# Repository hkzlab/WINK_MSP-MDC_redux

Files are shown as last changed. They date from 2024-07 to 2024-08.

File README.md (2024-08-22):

# MSP-MDC Redux

## DISCLAIMER

Any use of this project is **under your own responsibility**.
You will be responsible of checking the correct construction and functionality of your board.
By using this project You will agree that I cannot be held responsible if it will destroy any of your devices, damage your computer, burn down your house or whatever.

## Introduction

Wink is a 1985, breakout-style, arcade game by Midcoin.

The game uses off-the-shelf components for everything, but a bunch of circuitry, called the MSP-MDC module, that acts both as CPU and as 
security (scrambling addresses accessed by the CPU), is placed on 3 sandwiched PCBs encased in epoxy.
This was made to thwart bootleggers, but if something within this epoxied block dies, the whole game stops working.

I painstakingly pulled the block apart and chipped away the epoxy to recover the schematic.

This project contains files to build a compatible board that can be plugged in place of the original MSP-MDC.

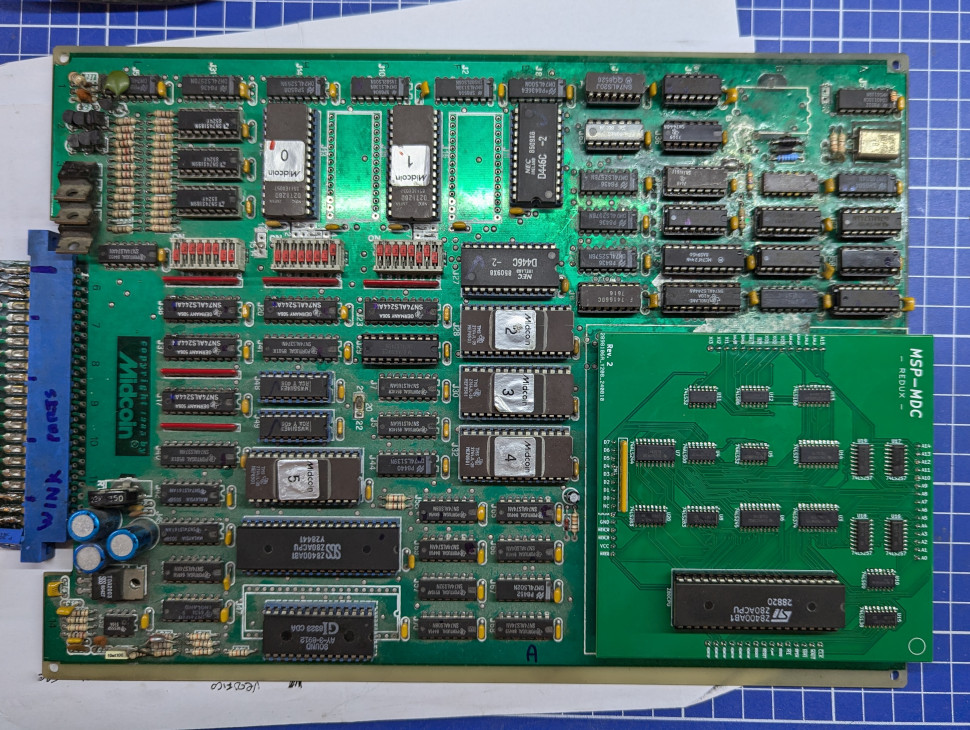
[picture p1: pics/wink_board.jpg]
Wink PCB + MSP-MDC redux


## Hardware

The board was designed with [KiCad](https://kicad.org/) EDA.

You can order boards directly from [PCBWay](https://www.pcbway.com/project/shareproject/MSP_MDC_Redux_c4e8a048.html)!

### Bill of Materials

| Component | Qty | Type / Value | Notes |
| --- | --- | --- | --- |
| C1 - C14 | 19  | 100nF / 1206 / ceramic | |
| R1, R2 |  2  | 1K / 1206 | |
| RN1 |  1  | 9-pin bussed 10K resistor array| |
| |  4  | 4x15pin 2.54mm straight headers| Mount on the 4 sides of the module |
| U2 |  1  | DIP-40 Z80A CPU | It's a good idea to socket this |
| U3, U14 |  2  | 74LS374 SO-20 | 5.3x12.6mm |
| U4 |  1  | 74ALS00 SOIC-14 | 3.9x8.7mm |
| U5 |  1  | 74ALS32 SOIC-14 | 3.9x8.7mm |
| U6 |  1  | 74LS245 SO-20 | 5.3x12.6mm |
| U7 |  1  | 74ALS244 SO-20 | 5.3x12.6mm |
| U8, U20 |  2  | 74LS283 SOIC-16 | 3.9x9.9mm |
| U10 |  1  | 74LS00 SOIC-14 | 3.9x8.7mm |
| U11 |  1  | 74LS32 SOIC-14 | 3.9x8.7mm |
| U12 |  1  | 74LS86 SOIC-14 | 3.9x8.7mm |
| U13 |  1  | 74LS166 SOIC-16 | 3.9x9.9mm |
| U15 |  1  | 74LS138 SOIC-16 | 3.9x9.9mm |
| U16 - U19 |  4  | 74LS257 SOIC-16 | 3.9x9.9mm |

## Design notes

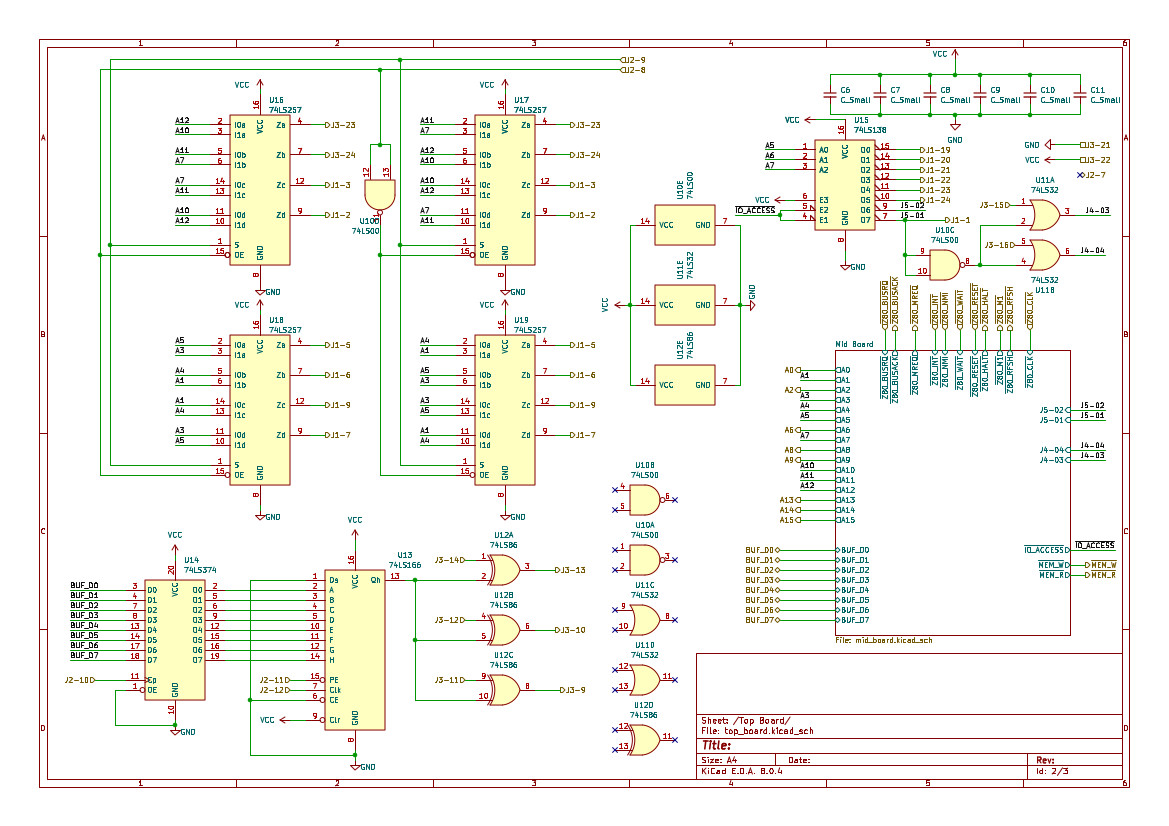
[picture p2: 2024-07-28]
MSP-MDC-Top Board.jpg

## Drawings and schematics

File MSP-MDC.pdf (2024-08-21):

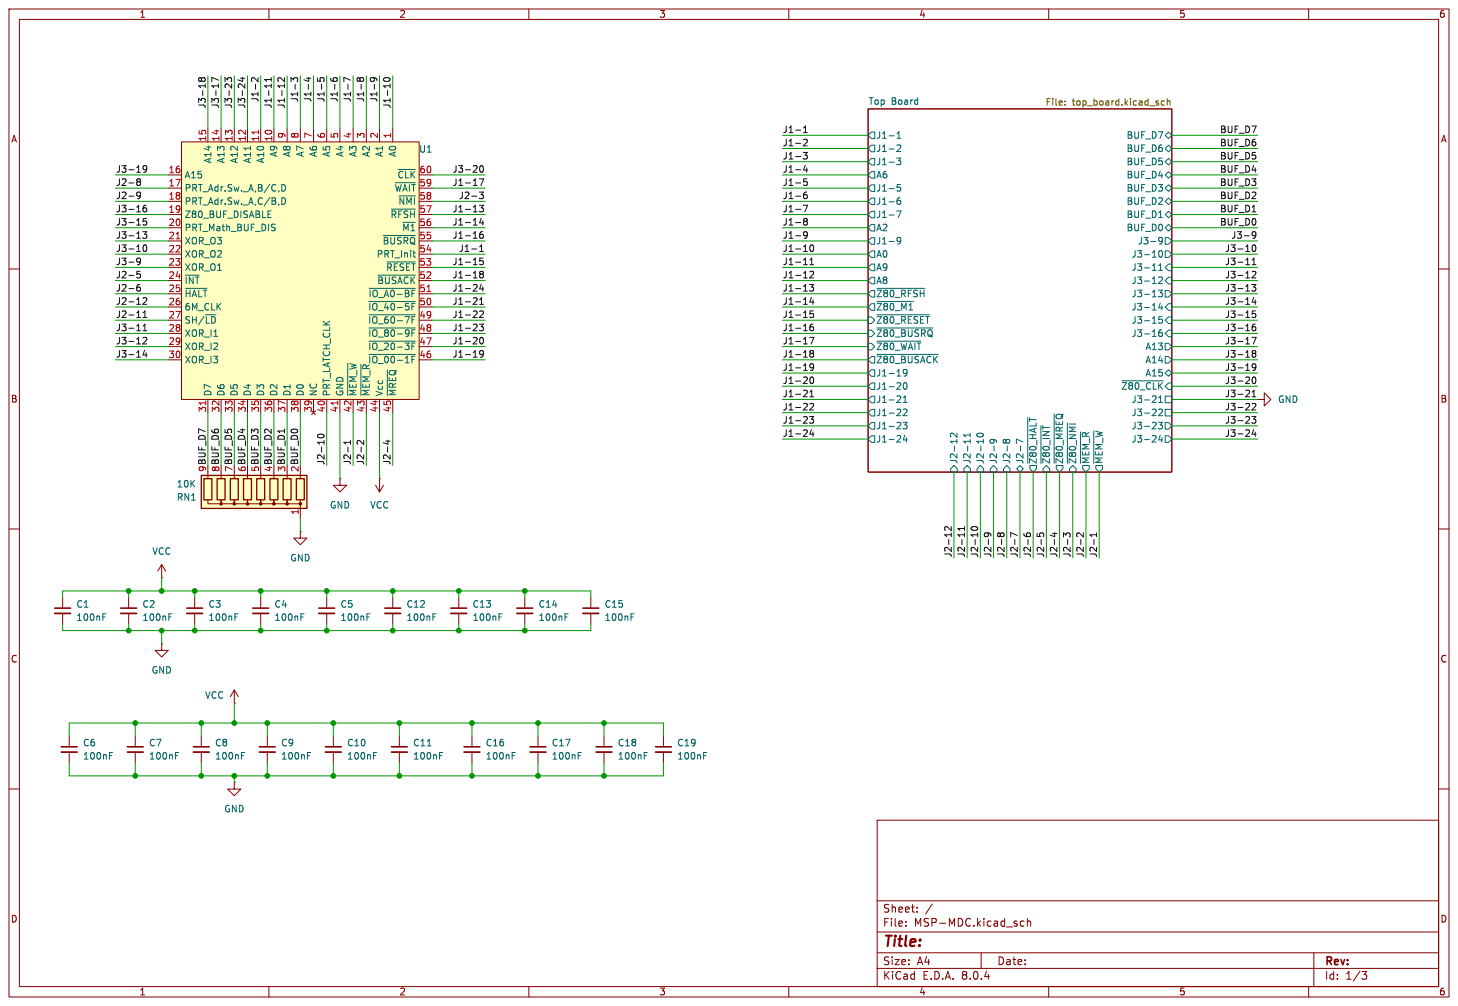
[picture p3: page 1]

5 ~{IO_40-5F}50 ~{IO_A0-BF}51 ~{BUSACK}52 ~{RESET} 53 PRT_Init 54 ~{BUSRQ}55 ~{M1}56 ~{RFSH} 57 ~{NMI}58 ~{WAIT} 59 A5

Id: 1/3 Title: File: MSP-MDC.kicad_sch Sheet: /

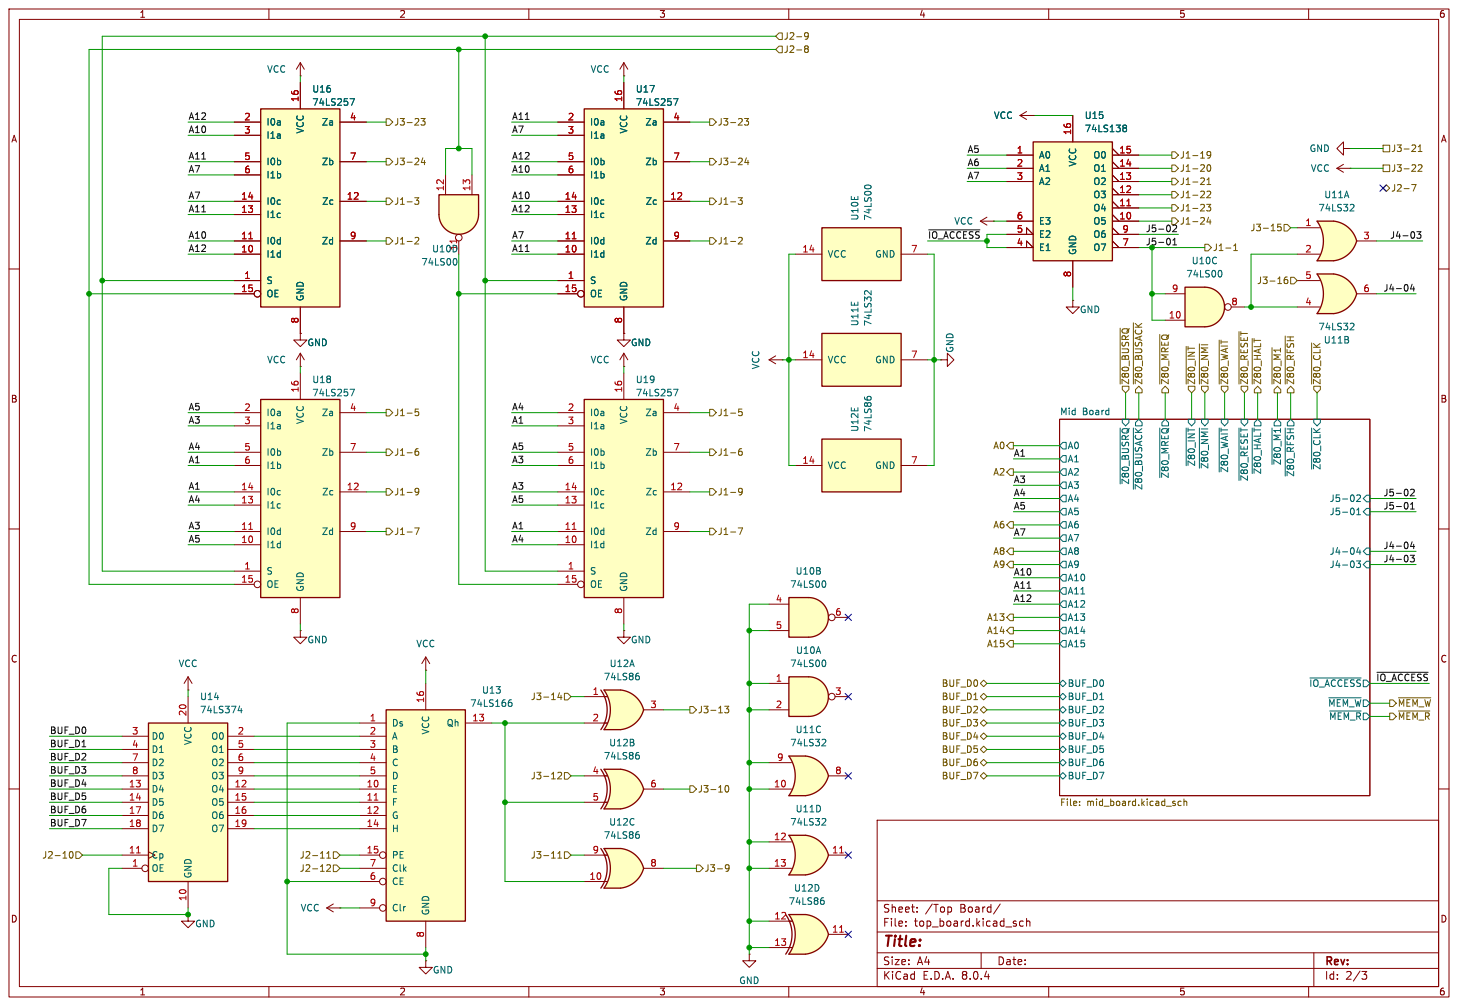
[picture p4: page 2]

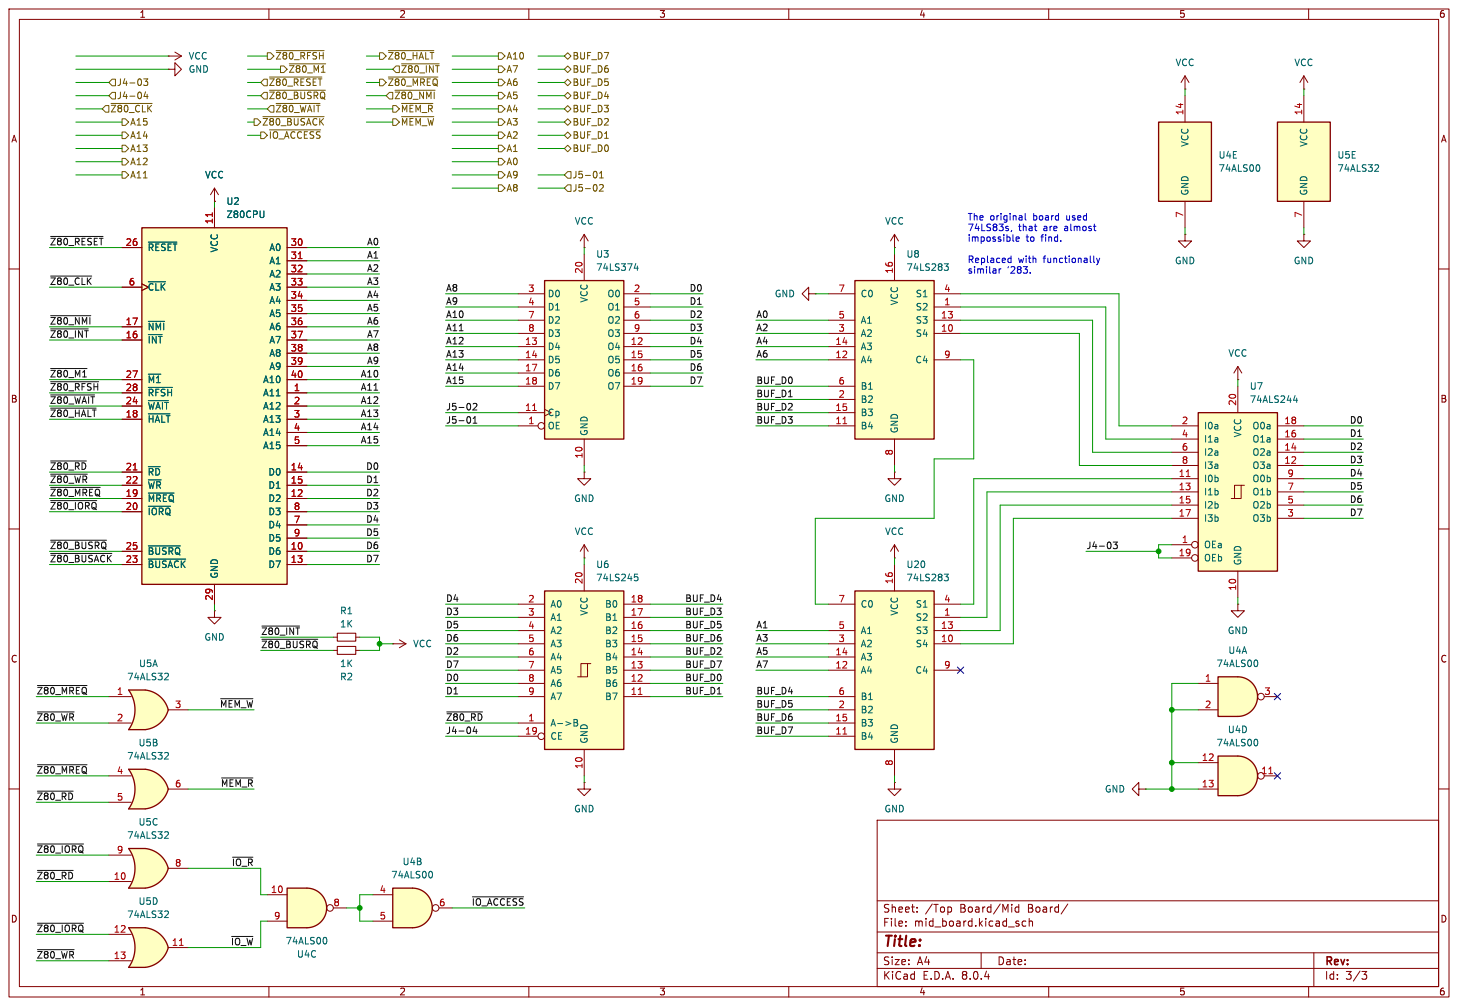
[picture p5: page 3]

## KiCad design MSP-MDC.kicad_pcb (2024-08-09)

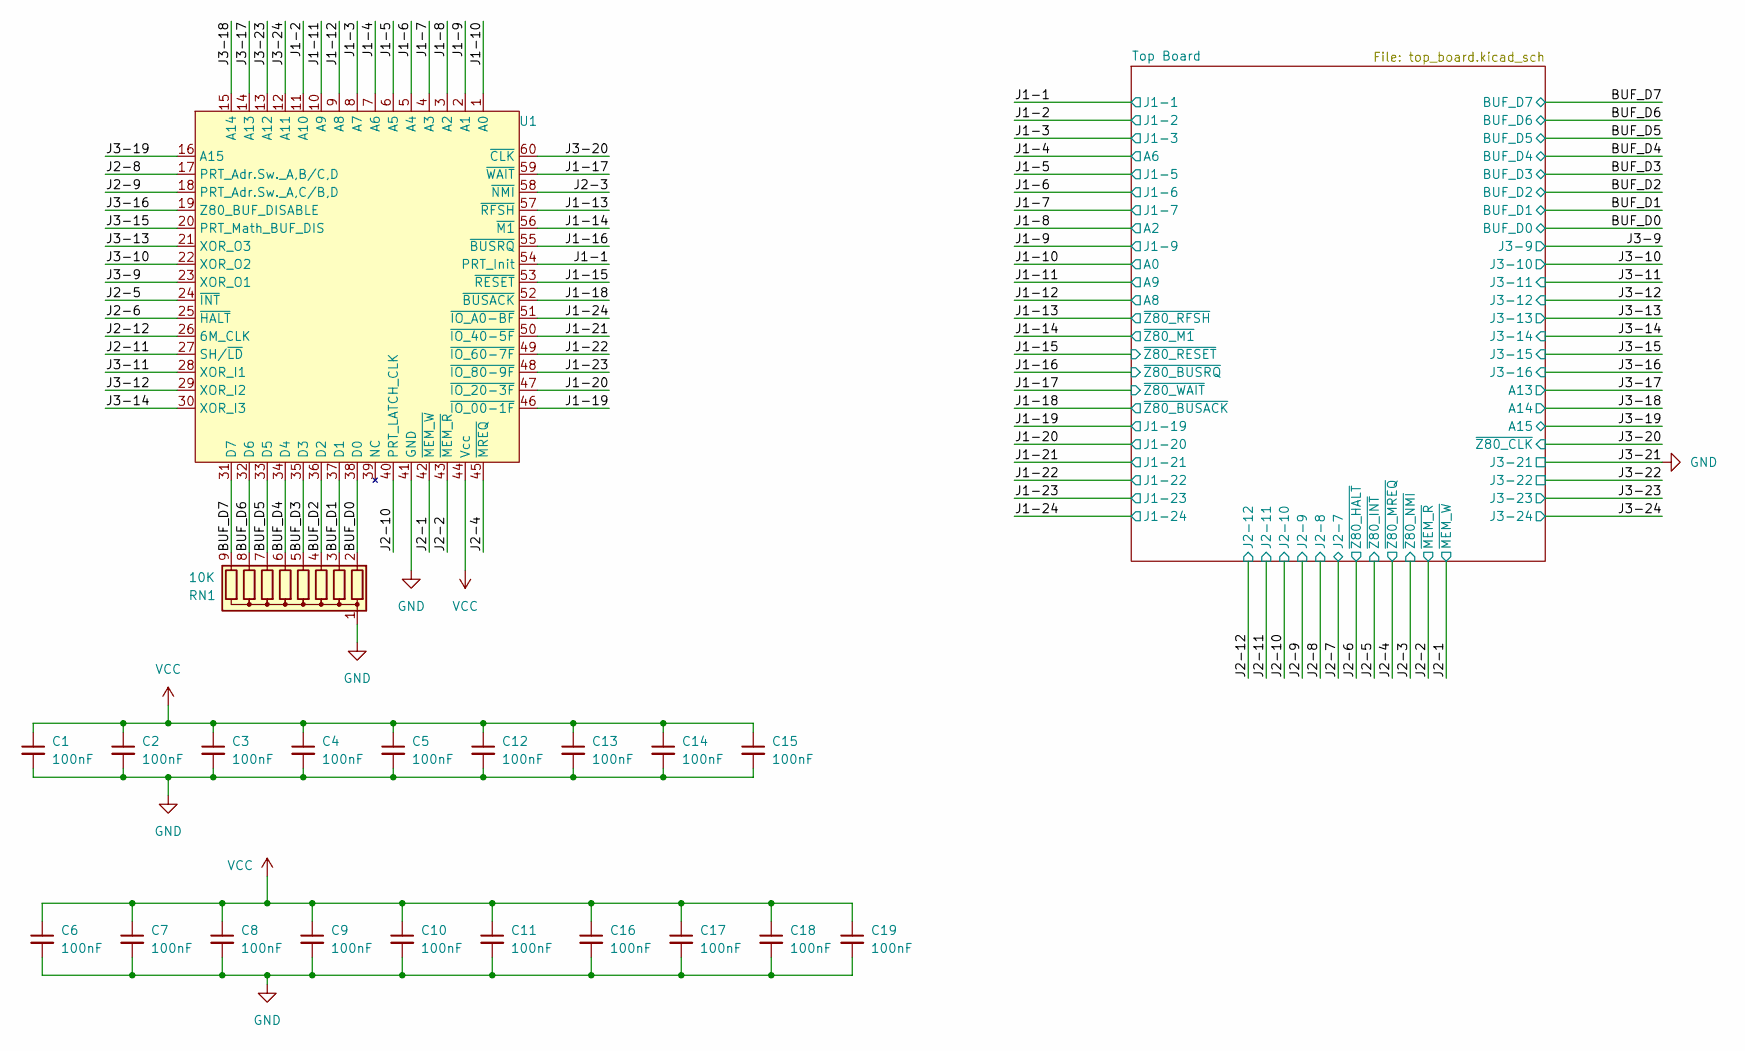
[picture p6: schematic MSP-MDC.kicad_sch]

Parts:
C1, C2, C3, C4, C5, C6, C7, C8, C9, C10, C11, C12, C13, C14, C15, C16, C17, C18, C19: 100nF; C_1206_3216Metric_Pad1.33x1.80mm_HandSolder
RN1: 10K; R_Array_SIP9
U1: MSP-MDC

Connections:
/BUF_D0: RN1.2 (R1), U1.38 (D0); also elsewhere on the board
/BUF_D1: RN1.3 (R2), U1.37 (D1); also elsewhere on the board
/BUF_D2: RN1.4 (R3), U1.36 (D2); also elsewhere on the board
/BUF_D3: RN1.5 (R4), U1.35 (D3); also elsewhere on the board
/BUF_D4: RN1.6 (R5), U1.34 (D4); also elsewhere on the board
/BUF_D5: RN1.7 (R6), U1.33 (D5); also elsewhere on the board
/BUF_D6: RN1.8 (R7), U1.32 (D6); also elsewhere on the board
/BUF_D7: RN1.9 (R8), U1.31 (D7); also elsewhere on the board
/J1-1: U1.54 (PRT_Init); also elsewhere on the board
/J1-2: U1.11 (A10); also elsewhere on the board
/J1-3: U1.8 (A7); also elsewhere on the board
/J1-4: U1.7 (A6); also elsewhere on the board
/J1-5: U1.6 (A5); also elsewhere on the board
/J1-6: U1.5 (A4); also elsewhere on the board
/J1-7: U1.4 (A3); also elsewhere on the board
/J1-8: U1.3 (A2); also elsewhere on the board
/J1-9: U1.2 (A1); also elsewhere on the board
/J1-10: U1.1 (A0); also elsewhere on the board
/J1-11: U1.10 (A9); also elsewhere on the board
/J1-12: U1.9 (A8); also elsewhere on the board
/J1-13: U1.57 (~RFSH); also elsewhere on the board
/J1-14: U1.56 (~M1); also elsewhere on the board
/J1-15: U1.53 (~RESET); also elsewhere on the board
/J1-16: U1.55 (~BUSRQ); also elsewhere on the board
/J1-17: U1.59 (~WAIT); also elsewhere on the board
/J1-18: U1.52 (~BUSACK); also elsewhere on the board
/J1-19: U1.46 (~IO_00-1F); also elsewhere on the board
/J1-20: U1.47 (~IO_20-3F); also elsewhere on the board
/J1-21: U1.50 (~IO_40-5F); also elsewhere on the board
/J1-22: U1.49 (~IO_60-7F); also elsewhere on the board
/J1-23: U1.48 (~IO_80-9F); also elsewhere on the board
/J1-24: U1.51 (~IO_A0-BF); also elsewhere on the board
/J2-1: U1.42 (~MEM_W); also elsewhere on the board
/J2-2: U1.43 (~MEM_R); also elsewhere on the board
/J2-3: U1.58 (~NMI); also elsewhere on the board
/J2-4: U1.45 (~MREQ); also elsewhere on the board
/J2-5: U1.24 (~INT); also elsewhere on the board
/J2-6: U1.25 (~HALT); also elsewhere on the board
/J2-8: U1.17 (PRT_Adr.Sw._A,B/C,D); also elsewhere on the board
/J2-9: U1.18 (PRT_Adr.Sw._A,C/B,D); also elsewhere on the board
/J2-10: U1.40 (PRT_LATCH_CLK); also elsewhere on the board
/J2-11: U1.27 (SH/~LD); also elsewhere on the board
/J2-12: U1.26 (6M_CLK); also elsewhere on the board
/J3-9: U1.23 (XOR_O1); also elsewhere on the board
/J3-10: U1.22 (XOR_O2); also elsewhere on the board
/J3-11: U1.28 (XOR_I1); also elsewhere on the board
/J3-12: U1.29 (XOR_I2); also elsewhere on the board
/J3-13: U1.21 (XOR_O3); also elsewhere on the board
/J3-14: U1.30 (XOR_I3); also elsewhere on the board
/J3-15: U1.20 (PRT_Math_BUF_DIS); also elsewhere on the board
/J3-16: U1.19 (Z80_BUF_DISABLE); also elsewhere on the board
/J3-17: U1.14 (A13); also elsewhere on the board
/J3-18: U1.15 (A14); also elsewhere on the board
/J3-19: U1.16 (A15); also elsewhere on the board
/J3-20: U1.60 (~CLK); also elsewhere on the board
/J3-23: U1.13 (A12); also elsewhere on the board
/J3-24: U1.12 (A11); also elsewhere on the board
GND: C1.2, C2.2, C3.2, C4.2, C5.2, C6.2, C7.2, C8.2, C9.2, C10.2, C11.2, C12.2, C13.2, C14.2, C15.2, C16.2, C17.2, C18.2, C19.2, RN1.1 (common), U1.41 (GND); also elsewhere on the board
VCC: C1.1, C2.1, C3.1, C4.1, C5.1, C6.1, C7.1, C8.1, C9.1, C10.1, C11.1, C12.1, C13.1, C14.1, C15.1, C16.1, C17.1, C18.1, C19.1, U1.44 (Vcc); also elsewhere on the board

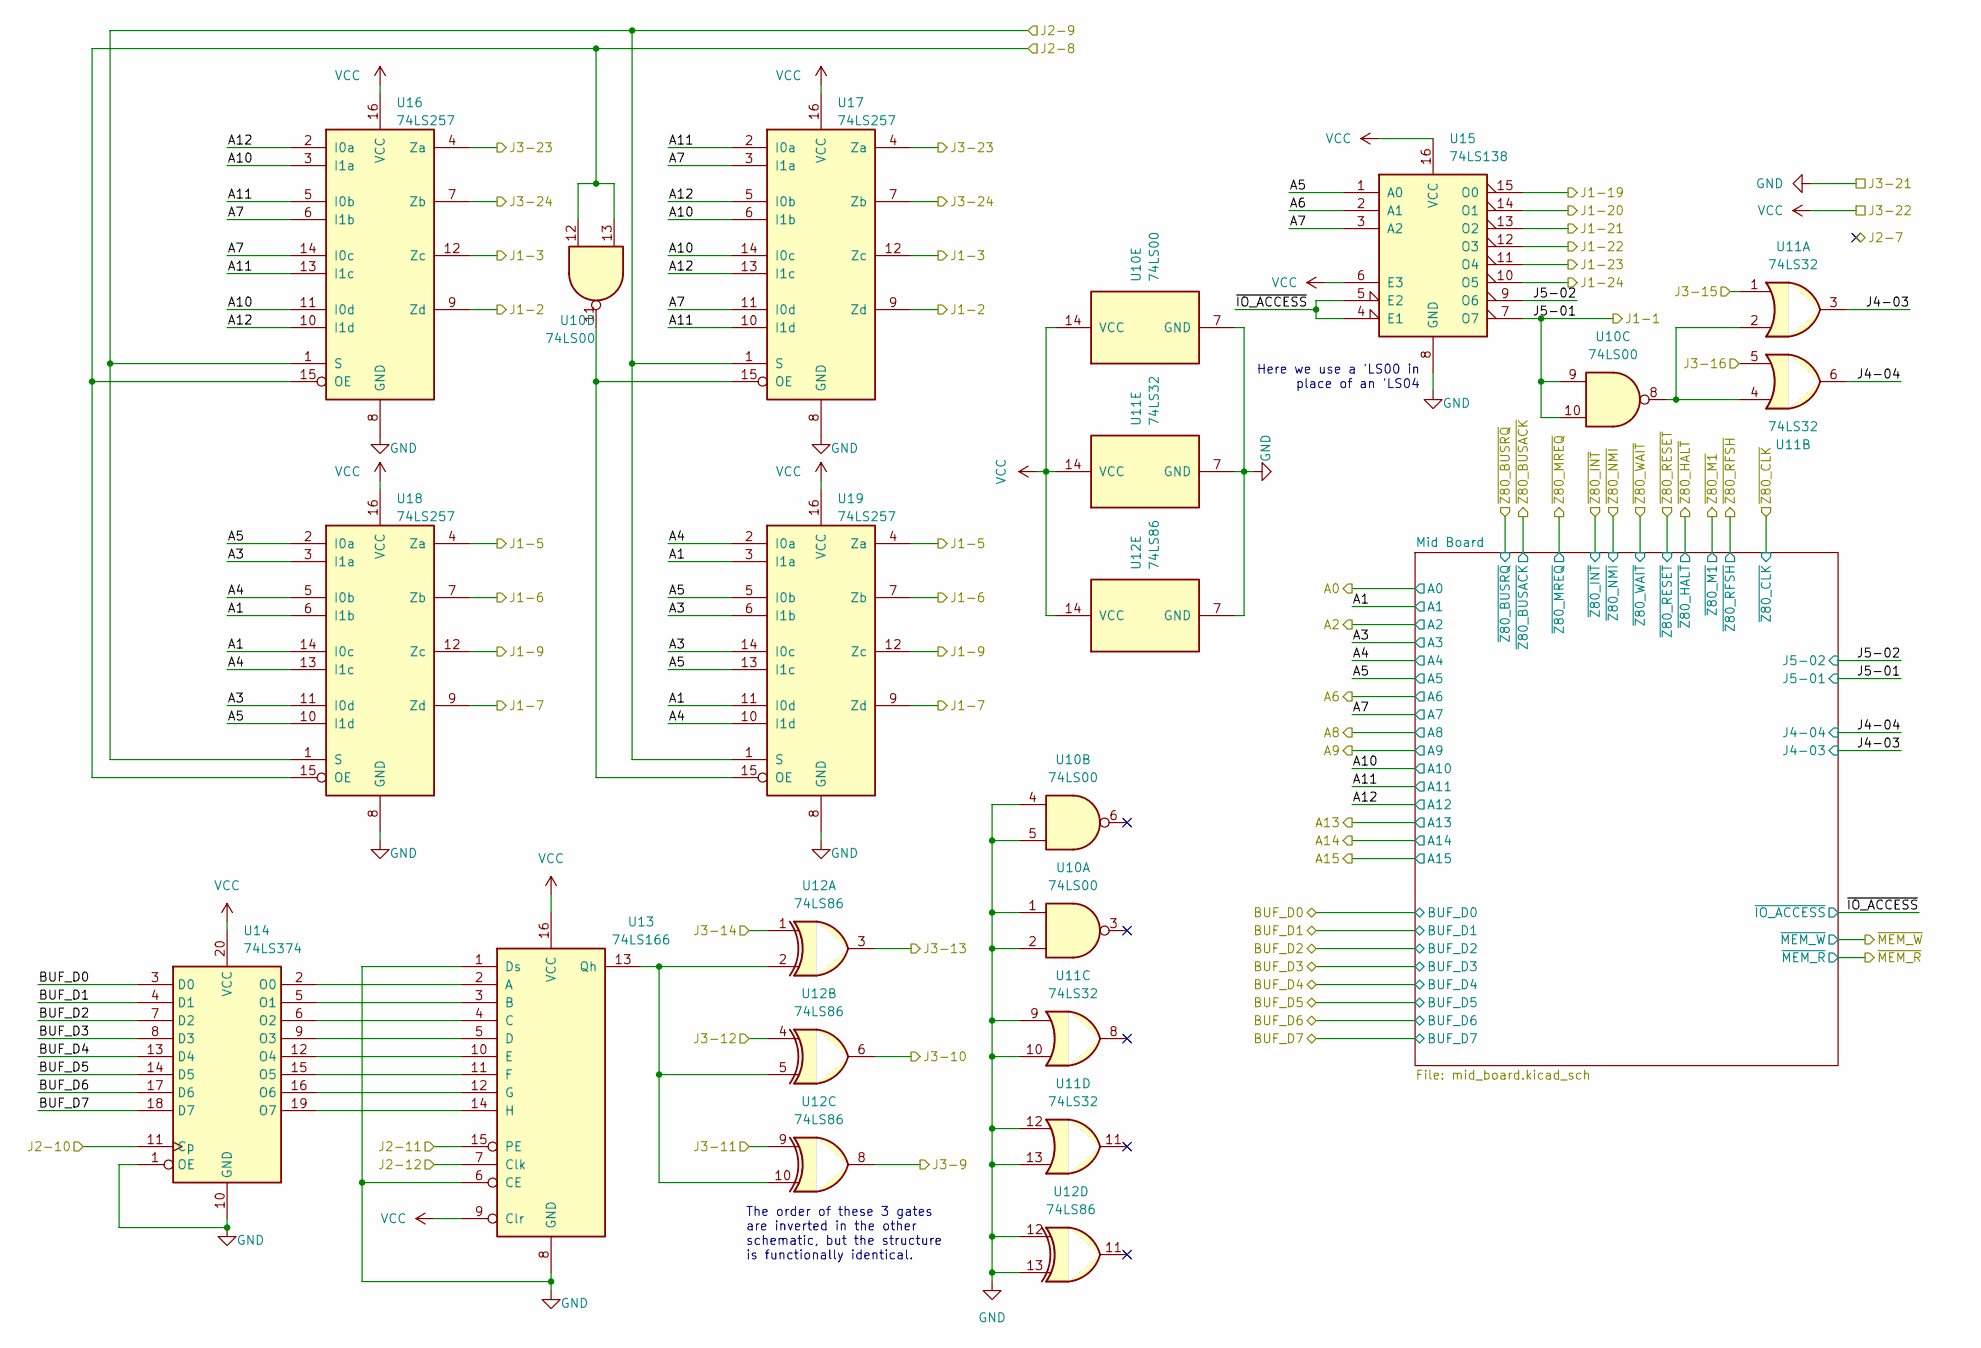
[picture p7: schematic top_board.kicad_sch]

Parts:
U10: 74LS00; SOIC-14_3.9x8.7mm_P1.27mm
U11: 74LS32; SOIC-14_3.9x8.7mm_P1.27mm
U12: 74LS86; SOIC-14_3.9x8.7mm_P1.27mm
U13: 74LS166; SOIC-16_3.9x9.9mm_P1.27mm
U14: 74LS374; SO-20_5.3x12.6mm_P1.27mm
U15: 74LS138; SOIC-16_3.9x9.9mm_P1.27mm
U16, U17, U18, U19: 74LS257; SOIC-16_3.9x9.9mm_P1.27mm

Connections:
/BUF_D0: U14.3 (D0); also elsewhere on the board
/BUF_D1: U14.4 (D1); also elsewhere on the board
/BUF_D2: U14.7 (D2); also elsewhere on the board
/BUF_D3: U14.8 (D3); also elsewhere on the board
/BUF_D4: U14.13 (D4); also elsewhere on the board
/BUF_D5: U14.14 (D5); also elsewhere on the board
/BUF_D6: U14.17 (D6); also elsewhere on the board
/BUF_D7: U14.18 (D7); also elsewhere on the board
/J1-1: U10.9, U10.10, U15.7 (O7); also elsewhere on the board
/J1-2: U16.9 (Zd), U17.9 (Zd); also elsewhere on the board
/J1-3: U16.12 (Zc), U17.12 (Zc); also elsewhere on the board
/J1-4: U15.2 (A1); also elsewhere on the board
/J1-5: U18.4 (Za), U19.4 (Za); also elsewhere on the board
/J1-6: U18.7 (Zb), U19.7 (Zb); also elsewhere on the board
/J1-7: U18.9 (Zd), U19.9 (Zd); also elsewhere on the board
/J1-9: U18.12 (Zc), U19.12 (Zc); also elsewhere on the board
/J1-19: U15.15 (O0); also elsewhere on the board
/J1-20: U15.14 (O1); also elsewhere on the board
/J1-21: U15.13 (O2); also elsewhere on the board
/J1-22: U15.12 (O3); also elsewhere on the board
/J1-23: U15.11 (O4); also elsewhere on the board
/J1-24: U15.10 (O5); also elsewhere on the board
/J2-8: U10.12, U10.13, U16.15 (OE), U18.15 (OE); also elsewhere on the board
/J2-9: U16.1 (S), U17.1 (S), U18.1 (S), U19.1 (S); also elsewhere on the board
/J2-10: U14.11 (Cp); also elsewhere on the board
/J2-11: U13.15 (PE); also elsewhere on the board
/J2-12: U13.7 (Clk); also elsewhere on the board
/J3-9: U12.8; also elsewhere on the board
/J3-10: U12.6; also elsewhere on the board
/J3-11: U12.9; also elsewhere on the board
/J3-12: U12.4; also elsewhere on the board
/J3-13: U12.3; also elsewhere on the board
/J3-14: U12.1; also elsewhere on the board
/J3-15: U11.1; also elsewhere on the board
/J3-16: U11.5; also elsewhere on the board
/J3-23: U16.4 (Za), U17.4 (Za); also elsewhere on the board
/J3-24: U16.7 (Zb), U17.7 (Zb); also elsewhere on the board
/Top Board/A1: U18.6 (I1b), U18.14 (I0c), U19.3 (I1a), U19.11 (I0d); also elsewhere on the board
/Top Board/A3: U18.3 (I1a), U18.11 (I0d), U19.6 (I1b), U19.14 (I0c); also elsewhere on the board
/Top Board/A4: U18.5 (I0b), U18.13 (I1c), U19.2 (I0a), U19.10 (I1d); also elsewhere on the board
/Top Board/A5: U15.1 (A0), U18.2 (I0a), U18.10 (I1d), U19.5 (I0b), U19.13 (I1c); also elsewhere on the board
/Top Board/A7: U15.3 (A2), U16.6 (I1b), U16.14 (I0c), U17.3 (I1a), U17.11 (I0d); also elsewhere on the board
/Top Board/A10: U16.3 (I1a), U16.11 (I0d), U17.6 (I1b), U17.14 (I0c); also elsewhere on the board
/Top Board/A11: U16.5 (I0b), U16.13 (I1c), U17.2 (I0a), U17.10 (I1d); also elsewhere on the board
/Top Board/A12: U16.2 (I0a), U16.10 (I1d), U17.5 (I0b), U17.13 (I1c); also elsewhere on the board
/Top Board/J4-03: U11.3; also elsewhere on the board
/Top Board/J4-04: U11.6; also elsewhere on the board
/Top Board/J5-02: U15.9 (O6); also elsewhere on the board
/Top Board/~IO_ACCESS: U15.4 (E1), U15.5 (E2); also elsewhere on the board
GND: U10.1, U10.2, U10.4, U10.5, U10.7 (GND), U11.7 (GND), U11.9, U11.10, U11.12, U11.13, U12.7 (GND), U12.12, U12.13, U13.1 (Ds), U13.6 (CE), U13.8 (GND), U14.1 (OE), U14.10 (GND), U15.8 (GND), U16.8 (GND), U17.8 (GND), U18.8 (GND), U19.8 (GND); also elsewhere on the board
unnamed: U10.8, U11.2, U11.4
unnamed: U13.2 (A), U14.2 (O0)
unnamed: U13.3 (B), U14.5 (O1)
unnamed: U13.4 (C), U14.6 (O2)
unnamed: U13.5 (D), U14.9 (O3)
unnamed: U13.10 (E), U14.12 (O4)
unnamed: U13.11 (F), U14.15 (O5)
unnamed: U13.12 (G), U14.16 (O6)
unnamed: U13.14 (H), U14.19 (O7)
unnamed: U12.2, U12.5, U12.10, U13.13 (Qh)
unnamed: U10.11, U17.15 (OE), U19.15 (OE)
VCC: U10.14 (VCC), U11.14 (VCC), U12.14 (VCC), U13.9 (Clr), U13.16 (VCC), U14.20 (VCC), U15.6 (E3), U15.16 (VCC), U16.16 (VCC), U17.16 (VCC), U18.16 (VCC), U19.16 (VCC); also elsewhere on the board

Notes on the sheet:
The order of these 3 gates are inverted in the other schematic, but the structure is functionally identical.
Here we use a 'LS00 in place of an 'LS04

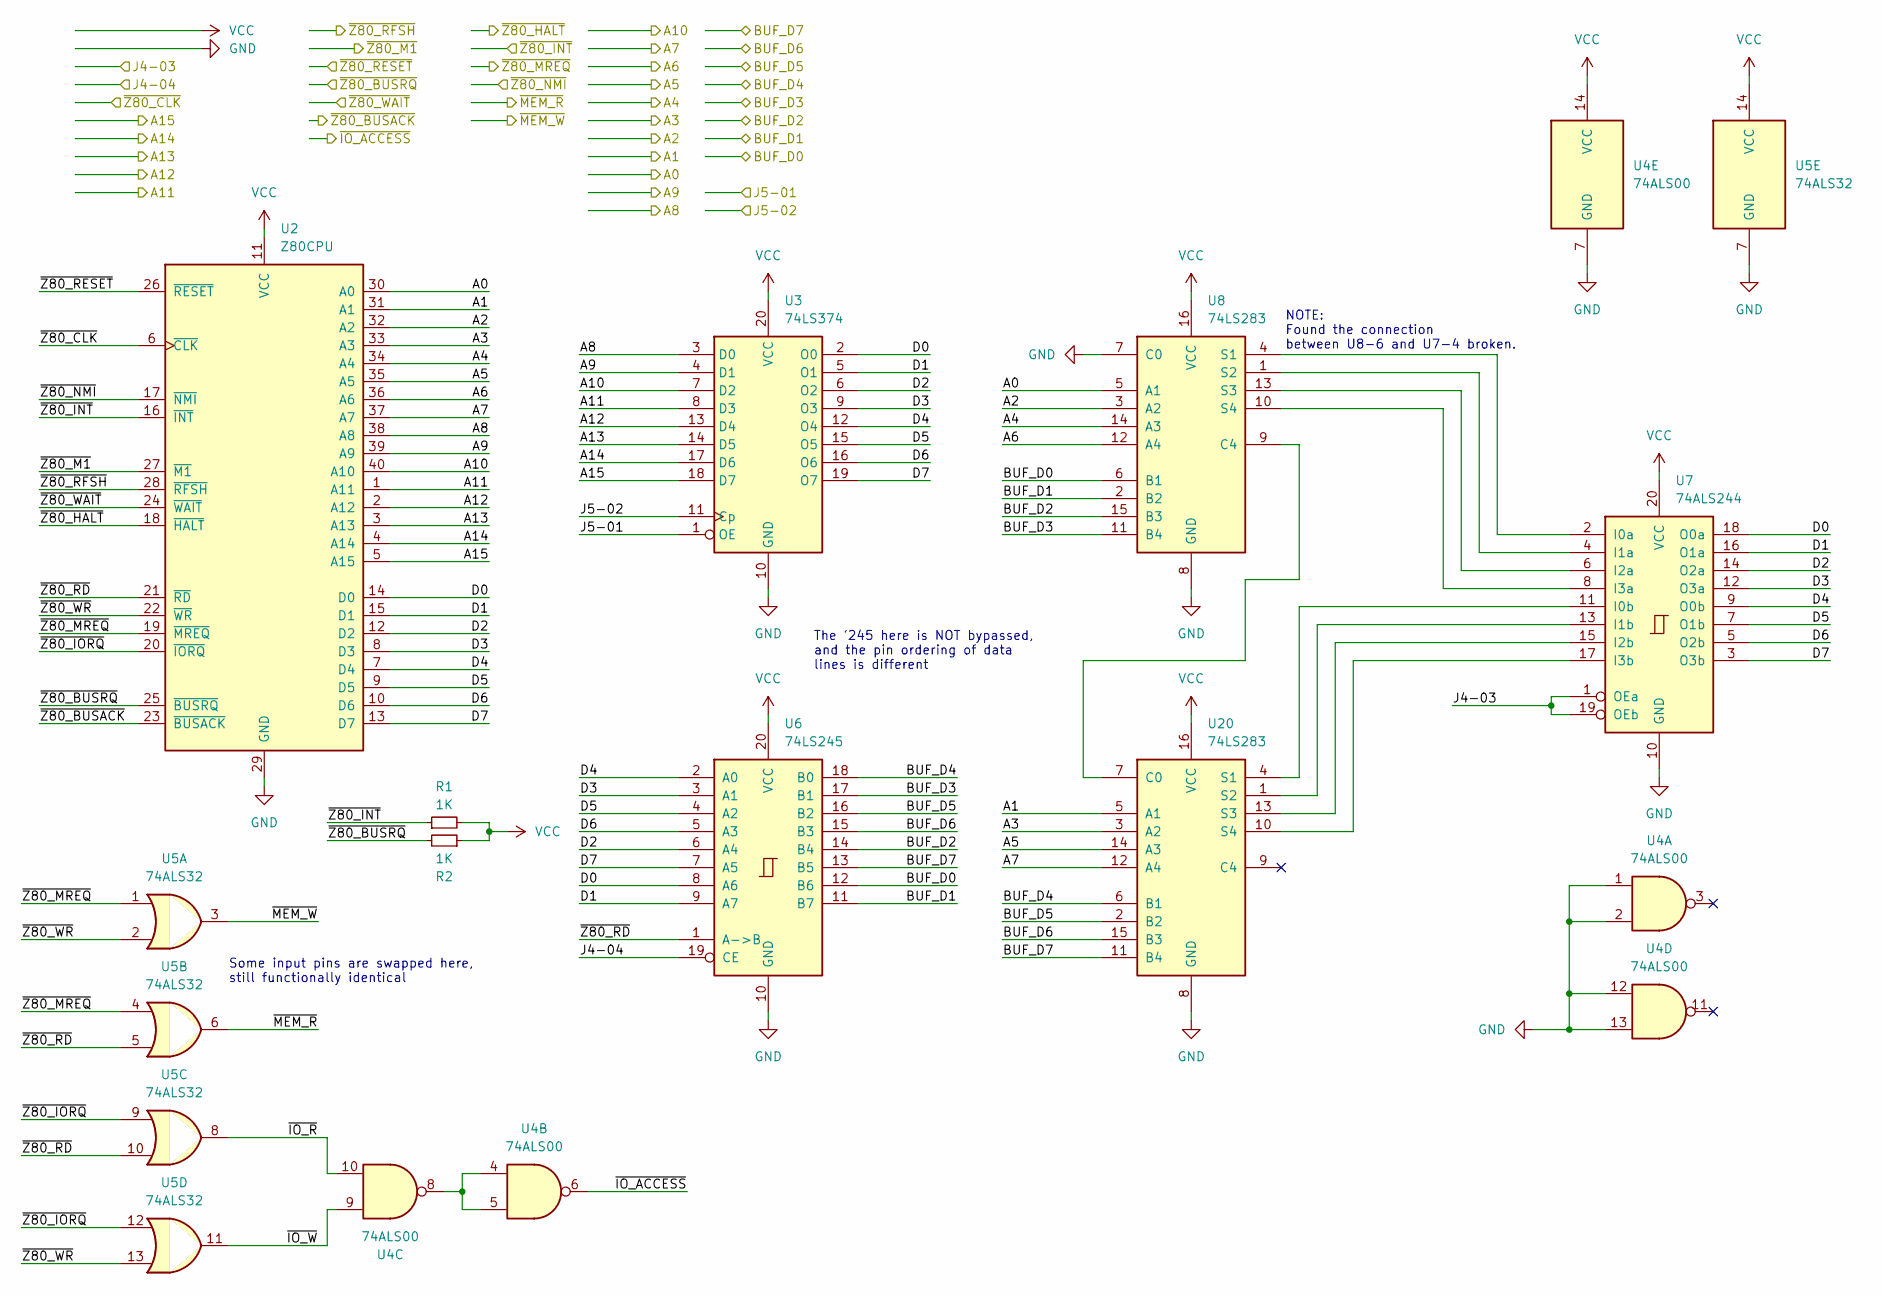
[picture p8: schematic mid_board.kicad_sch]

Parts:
R1, R2: 1K; R_1206_3216Metric_Pad1.30x1.75mm_HandSolder
U2: Z80CPU; DIP-40_W15.24mm_Socket
U3: 74LS374; SO-20_5.3x12.6mm_P1.27mm
U4: 74ALS00; SOIC-14_3.9x8.7mm_P1.27mm
U5: 74ALS32; SOIC-14_3.9x8.7mm_P1.27mm
U6: 74LS245; SO-20_5.3x12.6mm_P1.27mm
U7: 74ALS244; SO-20_5.3x12.6mm_P1.27mm
U8, U20: 74LS283; SOIC-16_3.9x9.9mm_P1.27mm

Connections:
/BUF_D0: U6.12 (B6), U8.6 (B1); also elsewhere on the board
/BUF_D1: U6.11 (B7), U8.2 (B2); also elsewhere on the board
/BUF_D2: U6.14 (B4), U8.15 (B3); also elsewhere on the board
/BUF_D3: U6.17 (B1), U8.11 (B4); also elsewhere on the board
/BUF_D4: U6.18 (B0), U20.6 (B1); also elsewhere on the board
/BUF_D5: U6.16 (B2), U20.2 (B2); also elsewhere on the board
/BUF_D6: U6.15 (B3), U20.15 (B3); also elsewhere on the board
/BUF_D7: U6.13 (B5), U20.11 (B4); also elsewhere on the board
/J1-1: U3.1 (OE); also elsewhere on the board
/J1-4: U2.36 (A6), U8.12 (A4); also elsewhere on the board
/J1-8: U2.32 (A2), U8.3 (A2); also elsewhere on the board
/J1-10: U2.30 (A0), U8.5 (A1); also elsewhere on the board
/J1-11: U2.39 (A9), U3.4 (D1); also elsewhere on the board
/J1-12: U2.38 (A8), U3.3 (D0); also elsewhere on the board
/J1-13: U2.28 (~RFSH); also elsewhere on the board
/J1-14: U2.27 (~M1); also elsewhere on the board
/J1-15: U2.26 (~RESET); also elsewhere on the board
/J1-16: R2.2, U2.25 (~BUSRQ); also elsewhere on the board
/J1-17: U2.24 (~WAIT); also elsewhere on the board
/J1-18: U2.23 (~BUSACK); also elsewhere on the board
/J2-1: U5.3; also elsewhere on the board
/J2-2: U5.6; also elsewhere on the board
/J2-3: U2.17 (~NMI); also elsewhere on the board
/J2-4: U2.19 (~MREQ), U5.1, U5.4; also elsewhere on the board
/J2-5: R1.1, U2.16 (~INT); also elsewhere on the board
/J2-6: U2.18 (~HALT); also elsewhere on the board
/J3-17: U2.3 (A13), U3.14 (D5); also elsewhere on the board
/J3-18: U2.4 (A14), U3.17 (D6); also elsewhere on the board
/J3-19: U2.5 (A15), U3.18 (D7); also elsewhere on the board
/J3-20: U2.6 (~CLK); also elsewhere on the board
/Top Board/A1: U2.31 (A1), U20.5 (A1); also elsewhere on the board
/Top Board/A3: U2.33 (A3), U20.3 (A2); also elsewhere on the board
/Top Board/A4: U2.34 (A4), U8.14 (A3); also elsewhere on the board
/Top Board/A5: U2.35 (A5), U20.14 (A3); also elsewhere on the board
/Top Board/A7: U2.37 (A7), U20.12 (A4); also elsewhere on the board
/Top Board/A10: U2.40 (A10), U3.7 (D2); also elsewhere on the board
/Top Board/A11: U2.1 (A11), U3.8 (D3); also elsewhere on the board
/Top Board/A12: U2.2 (A12), U3.13 (D4); also elsewhere on the board
/Top Board/J4-03: U7.1 (OEa), U7.19 (OEb); also elsewhere on the board
/Top Board/J4-04: U6.19 (CE); also elsewhere on the board
/Top Board/J5-02: U3.11 (Cp); also elsewhere on the board
/Top Board/Mid Board/D0: U2.14 (D0), U3.2 (O0), U6.8 (A6), U7.18 (O0a)
/Top Board/Mid Board/D1: U2.15 (D1), U3.5 (O1), U6.9 (A7), U7.16 (O1a)
/Top Board/Mid Board/D2: U2.12 (D2), U3.6 (O2), U6.6 (A4), U7.14 (O2a)
/Top Board/Mid Board/D3: U2.8 (D3), U3.9 (O3), U6.3 (A1), U7.12 (O3a)
/Top Board/Mid Board/D4: U2.7 (D4), U3.12 (O4), U6.2 (A0), U7.9 (O0b)
/Top Board/Mid Board/D5: U2.9 (D5), U3.15 (O5), U6.4 (A2), U7.7 (O1b)
/Top Board/Mid Board/D6: U2.10 (D6), U3.16 (O6), U6.5 (A3), U7.5 (O2b)
/Top Board/Mid Board/D7: U2.13 (D7), U3.19 (O7), U6.7 (A5), U7.3 (O3b)
/Top Board/Mid Board/~IO_R: U4.10, U5.8
/Top Board/Mid Board/~IO_W: U4.9, U5.11
/Top Board/Mid Board/~Z80_IORQ: U2.20 (~IORQ), U5.9, U5.12
/Top Board/Mid Board/~Z80_RD: U2.21 (~RD), U5.5, U5.10, U6.1 (A->B)
/Top Board/Mid Board/~Z80_WR: U2.22 (~WR), U5.2, U5.13
/Top Board/~IO_ACCESS: U4.6; also elsewhere on the board
GND: U2.29 (GND), U3.10 (GND), U4.1, U4.2, U4.7 (GND), U4.12, U4.13, U5.7 (GND), U6.10 (GND), U7.10 (GND), U8.7 (C0), U8.8 (GND), U20.8 (GND); also elsewhere on the board
unnamed: U4.4, U4.5, U4.8
unnamed: U7.2 (I0a), U8.4 (S1)
unnamed: U7.4 (I1a), U8.1 (S2)
unnamed: U7.6 (I2a), U8.13 (S3)
unnamed: U7.8 (I3a), U8.10 (S4)
unnamed: U8.9 (C4), U20.7 (C0)
unnamed: U7.11 (I0b), U20.4 (S1)
unnamed: U7.13 (I1b), U20.1 (S2)
unnamed: U7.15 (I2b), U20.13 (S3)
unnamed: U7.17 (I3b), U20.10 (S4)
VCC: R1.2, R2.1, U2.11 (VCC), U3.20 (VCC), U4.14 (VCC), U5.14 (VCC), U6.20 (VCC), U7.20 (VCC), U8.16 (VCC), U20.16 (VCC); also elsewhere on the board

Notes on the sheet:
The '245 here is NOT bypassed, and the pin ordering of data lines is different
Some input pins are swapped here, still functionally identical
NOTE: Found the connection between U8-6 and U7-4 broken.

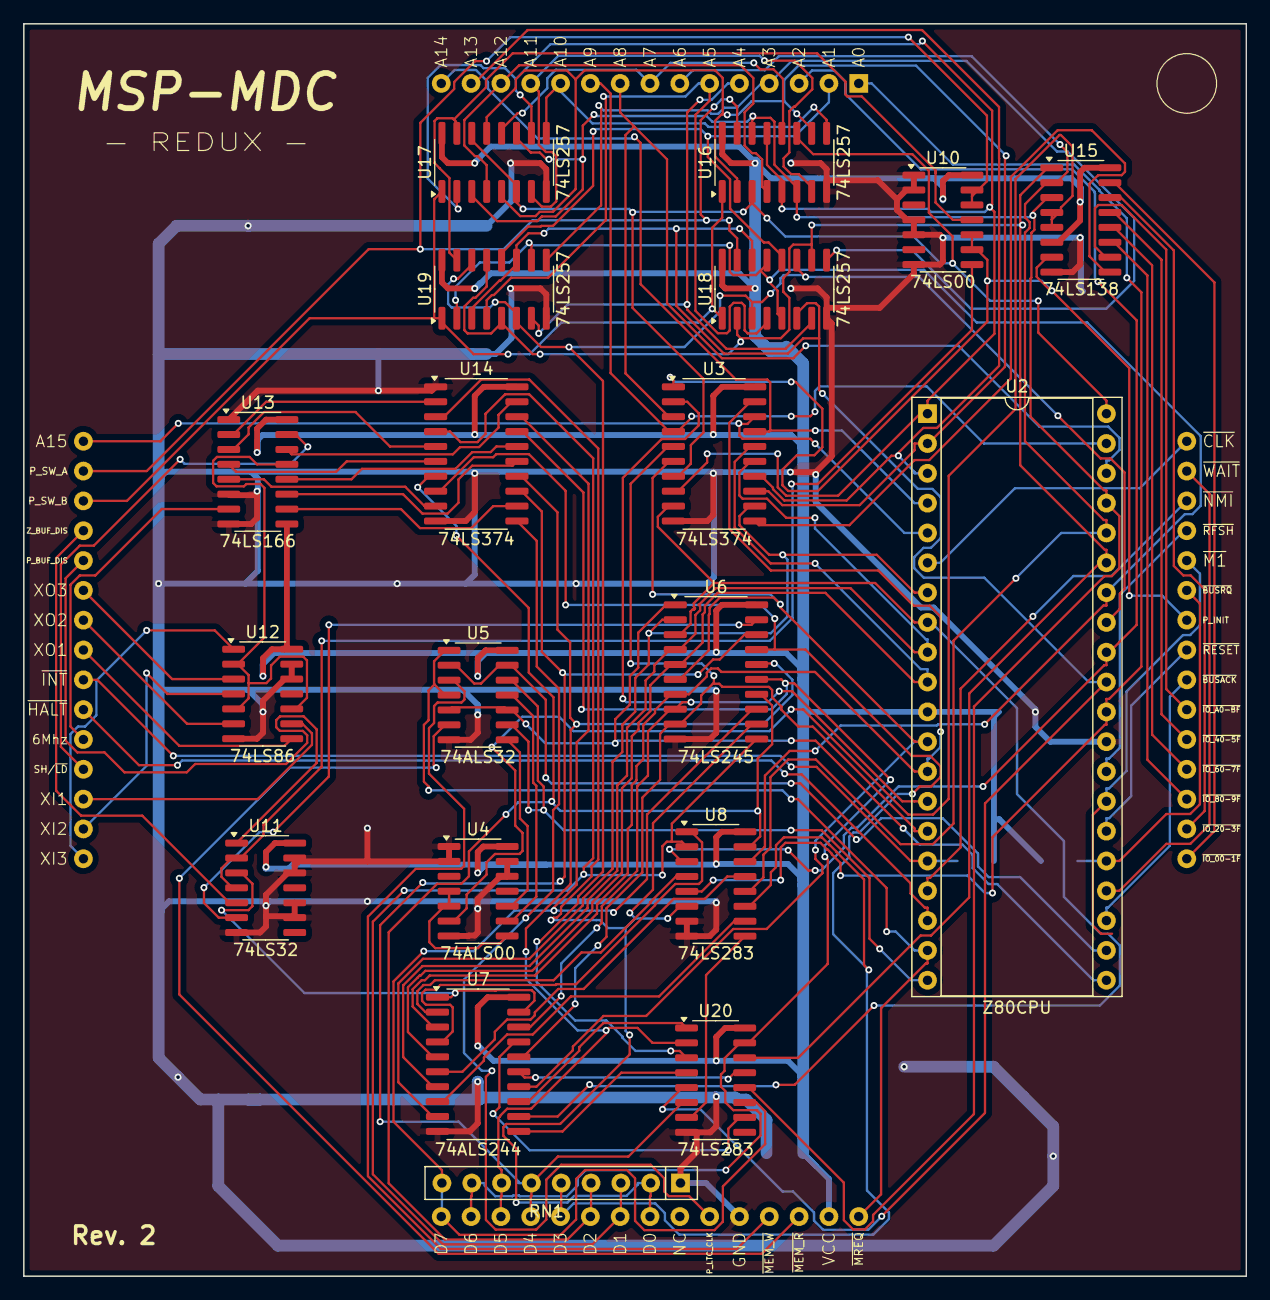
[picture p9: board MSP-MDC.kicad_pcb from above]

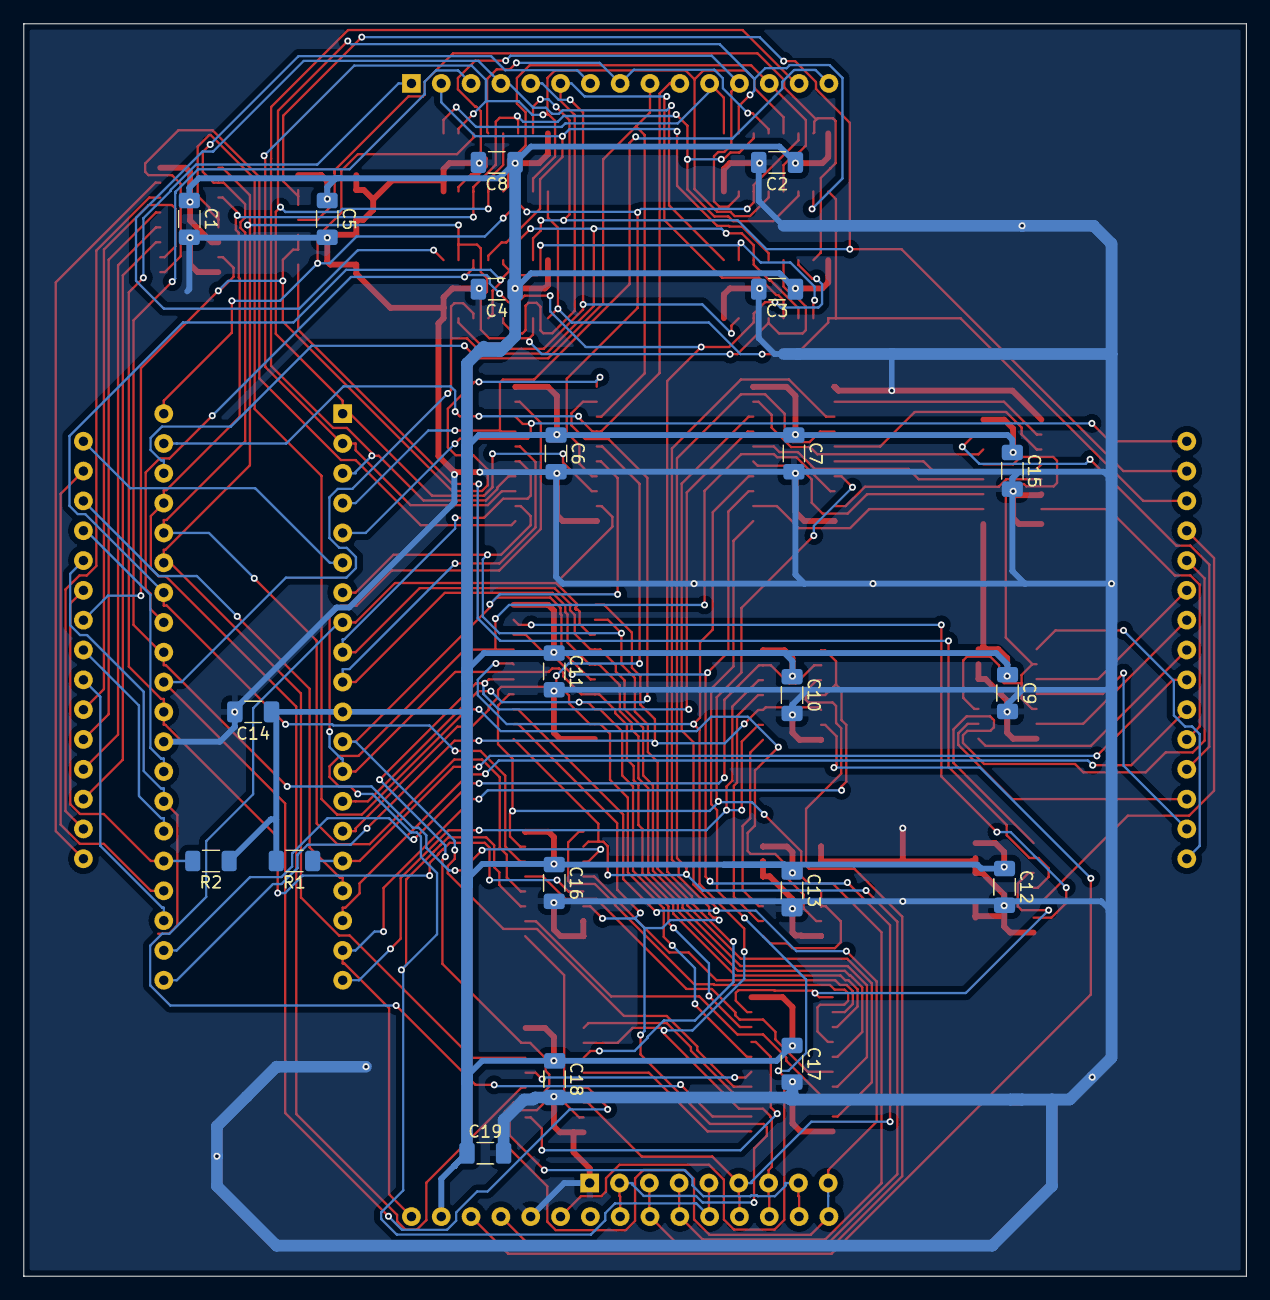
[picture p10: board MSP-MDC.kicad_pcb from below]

Board: 2 copper layers, 104.1 x 106.7 mm, 41 parts (21 on the bottom side), 105 nets.

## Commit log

2024-07-28 import msp-mdc project
    [MSP-MDC.kicad_pcb, MSP-MDC.kicad_sch, mid_board.kicad_sch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]
2024-07-28 Added some basic traces for power
    [MSP-MDC.kicad_pcb, MSP-MDC.kicad_sch, mid_board.kicad_sch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]
2024-07-28 Import routing for the first revision
    [MSP-MDC.kicad_pcb]
2024-08-07 Reduce size of the board to match original
    [MSP-MDC.kicad_pcb]
2024-08-07 Resize the board
    [MSP-MDC.kicad_pcb]
2024-08-09 Fix adder bit ordering
    [mid_board.kicad_sch, top_board.kicad_sch]
2024-08-09 Update board fixing adder issues
    [MSP-MDC.kicad_pcb, MSP-MDC.kicad_sch, mid_board.kicad_sch]
2024-08-21 Removed some text from schematic, added some more, generate PDF
    [mid_board.kicad_sch, top_board.kicad_sch]
2024-08-21 Mention PCBWay, update the readme
